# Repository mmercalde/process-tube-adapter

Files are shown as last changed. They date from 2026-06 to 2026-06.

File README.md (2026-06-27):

# Process-Tube Adapter (3D-printable, R600a)

A printable reimplementation of the Robinair 12458 **process-tube adapter** — the tool
that clamps onto a sealed system's copper **process stub** so you can pull a vacuum and
recharge without flaring the tube. Designed for **R600a (isobutane)** domestic
refrigeration, where working pressures are low and the real requirement is **vacuum
integrity**, not high-pressure containment.

The rigid parts are printed; the **seals are purchased O-rings**. Nothing safety-critical
relies on a printed sealing surface.

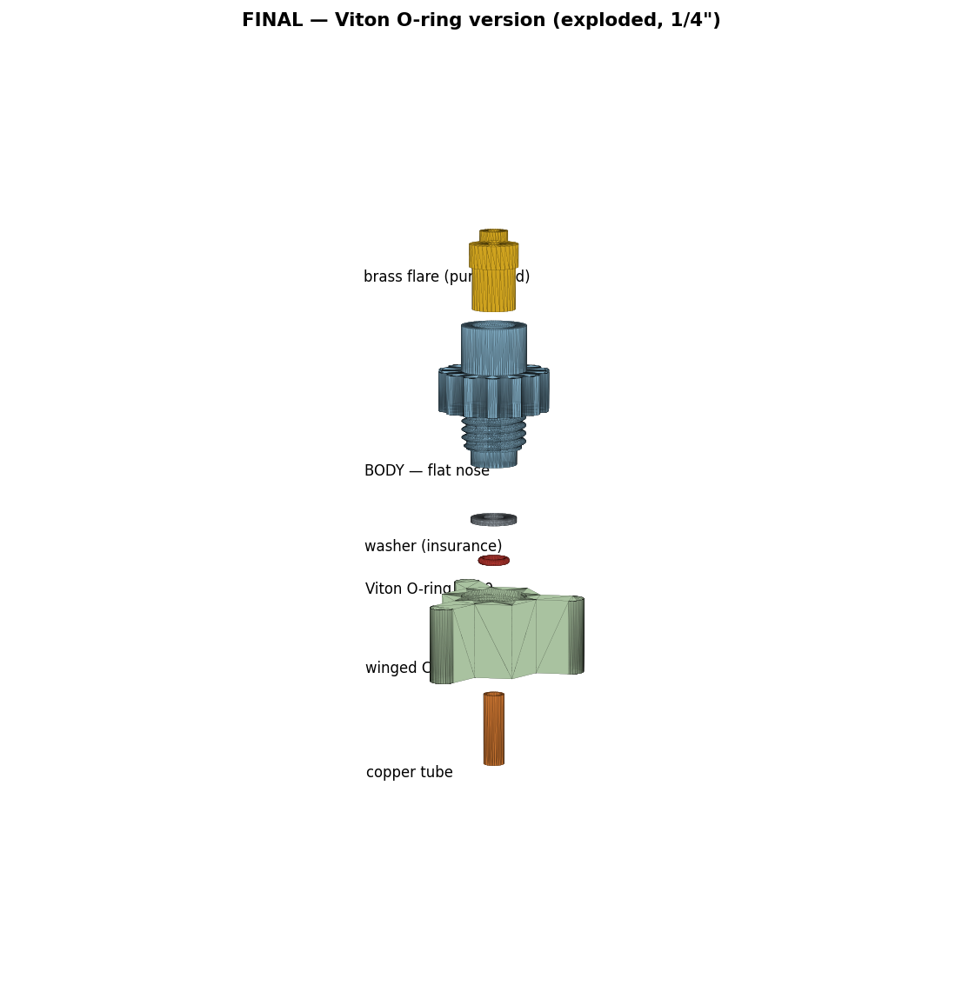
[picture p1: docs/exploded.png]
exploded


## How it works

One common **body** screws into a per-size **cap**. The copper stub slides up through the
cap's reinforced floor. Inside the cap's 17 mm bore sits a thick **channel washer** that carries **two standard O-rings** in edge grooves:

- the **outer ring** seals radially against the **17 mm cap bore**
- the **inner ring** seals radially against the **copper tube OD**

This splits the two sealing jobs the original Robinair crammed into one fat custom seal —
so both rings are common catalog sizes. The body's **clearance plunger nose** drives the
sandwich down; crush is **thread-driven with no hard stop**, so FDM tolerance variation
changes only how far you thread, never whether the rings seal. Refrigerant exits the open
cut end of the stub, up the body bore, to the hose.

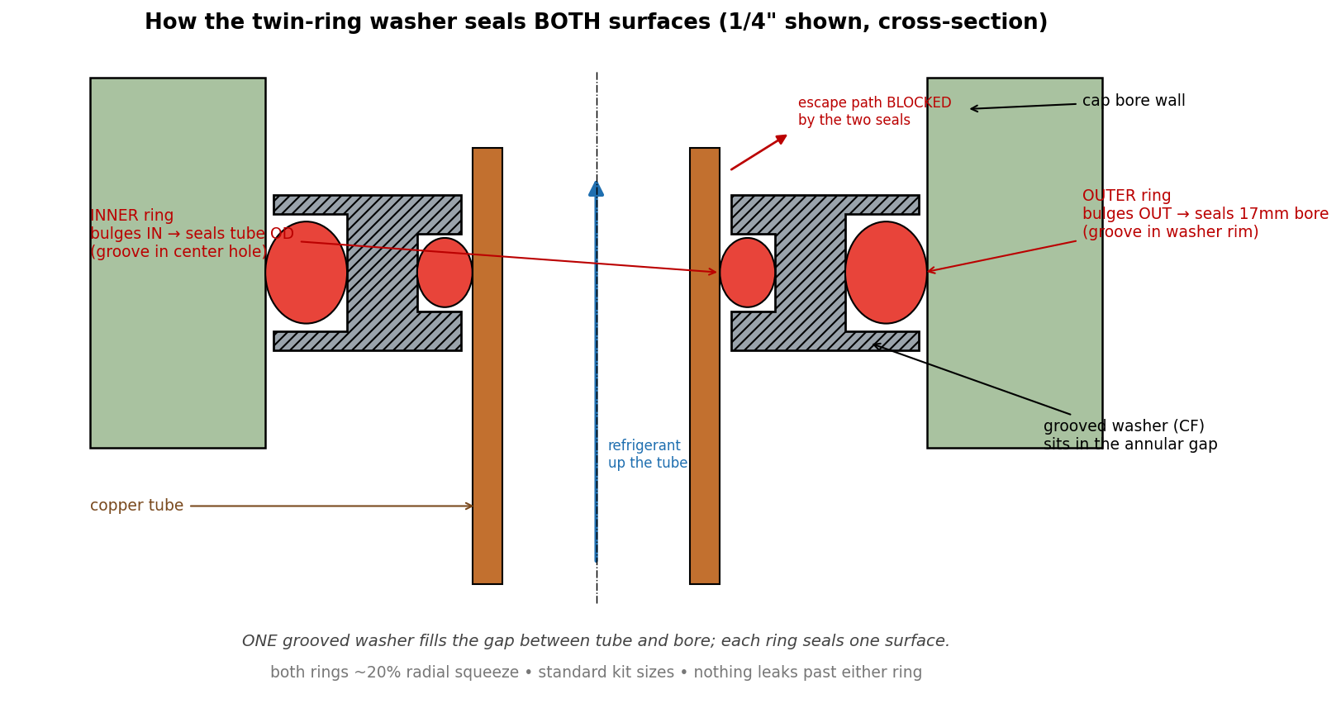
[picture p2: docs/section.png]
section


## Sealing — design notes

- **Reinforced 4.5 mm floor.** An earlier 2.5 mm floor buckled under crush load; the floor
  is now a solid anvil with only a tube-clearance hole.
- **No bottoming shoulder.** The plunger nose (Ø15 in the 17 bore) never lands metal-to-
  metal — the rings always take the load. Tighten until firm.
- **Edge grooves, ~20% squeeze.** The outer ring sits in a groove in the washer rim
  (root Ø12.81, vs the 17 bore); the inner ring sits in a groove in the center hole
  (root = tube OD + 2.85). Tune `SQUEEZE` in `generate.py` after a test fit.

## Bill of materials

Per assembly:
- 1 x printed **body** (shared across all tube sizes)
- 1 x printed **cap** for the tube size in use
- 1 x printed **channel washer** (the sealing element) + 1 x printed **backer washer**
- 1 x **outer O-ring** (seals the bore) + 1 x **inner O-ring** (seals the tube)
- 1 x **brass 1/4" SAE male-flare x 1/4" MNPT** adapter for the hose (threads into the body boss)
- Thread sealant (PTFE paste) for the brass-into-boss joint

### Tube size -> cap -> O-rings

| Tube OD | Cap / washers | Outer ring (bore) | Inner ring (tube) |
|---|---|---|---|
| 3/16" | `*_3-16` | A112 (12.37x2.62) | A008 (4.47x1.78)  |
| 1/4" | `*_1-4` | A112 | A010 (6.07x1.78)  |
| 5/16" | `*_5-16` | A112 | A011 (7.65x1.78)  |
| 3/8" | `*_3-8` | A112 | A012 (9.25x1.78)  |

The **outer ring is the same A112 for all four caps** (always sealing the 17 mm bore);
only the inner ring changes with tube size. Viton/FKM 75 Shore A recommended.

## Printing

- **Body + caps + washers:** PA-CF or PETG-CF, >=4 walls, 0.2 mm layers.
- Print the **body boss-up** so the NPT threads aren't on a support interface.
- Vertical circular holes run undersized on many printers — run X-Y hole compensation
  (~+0.15 mm) and verify the gland bore on a test print before committing all four.

## Assembly

1. Tap the body boss **1/4" NPT** (the Ø11.1 mm bore is the tap-drill — no drilling). Thread
   in the brass flare adapter with PTFE paste.
2. Drop the outer ring into the washers' outer pockets and the inner ring into the inner
   pockets; bring the washer pair together around the cut stub.
3. Slide the cap over the stub, thread the body in **by hand** until firm (wings + flutes
   give the grip — no wrench at R600a pressures).
4. Connect the charging hose to the brass flare. Evacuate / recharge.

## Verify before live use

Pull a vacuum on an assembled cap on a scrap stub and watch a micron gauge. If it creeps,
deepen the groove(s) slightly (`OG_D`/`IG_D`) for more squeeze and reprint the washers.
**R600a is flammable** — observe ventilation and ignition discipline.

## Regenerating / modifying

Every dimension is a named constant at the top of `generate.py`:

```bash
pip install build123d bd_warehouse
python3 generate.py        # writes ./stl and ./step
```

`.step` files open natively in FreeCAD / Fusion / Onshape for hands-on edits.

## License

MIT — see [LICENSE](LICENSE).

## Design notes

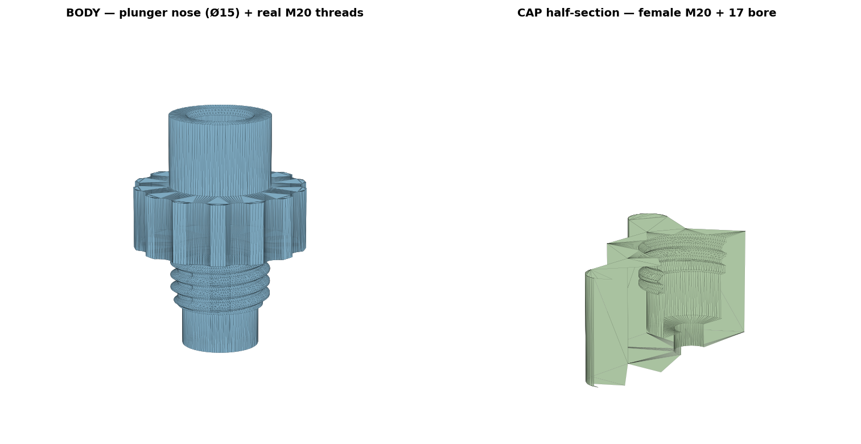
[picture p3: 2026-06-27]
docs/threads.png

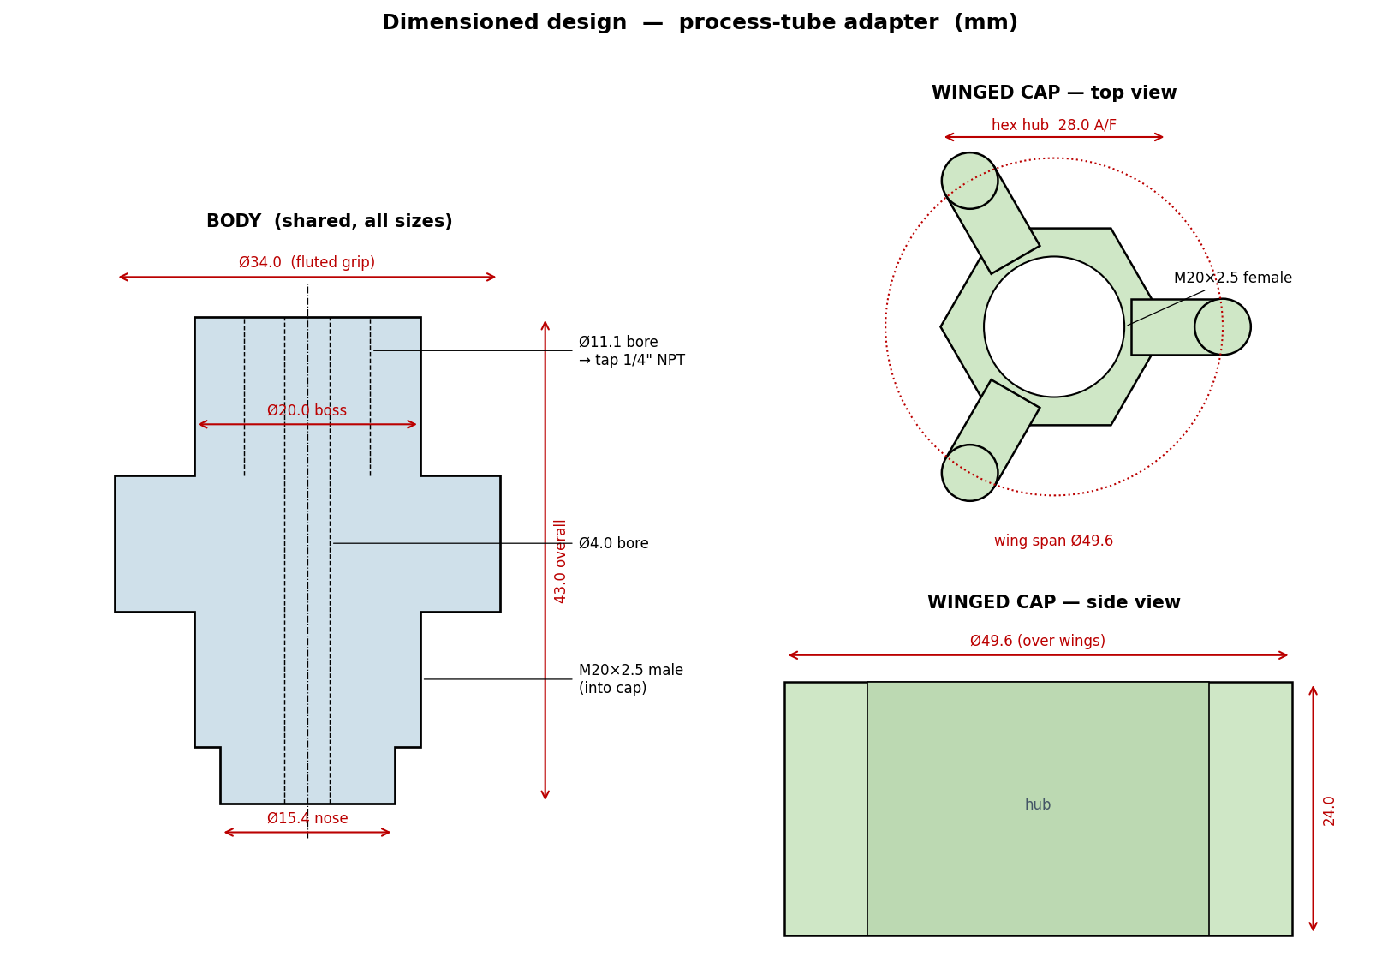
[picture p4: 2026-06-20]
docs/dimensioned.png

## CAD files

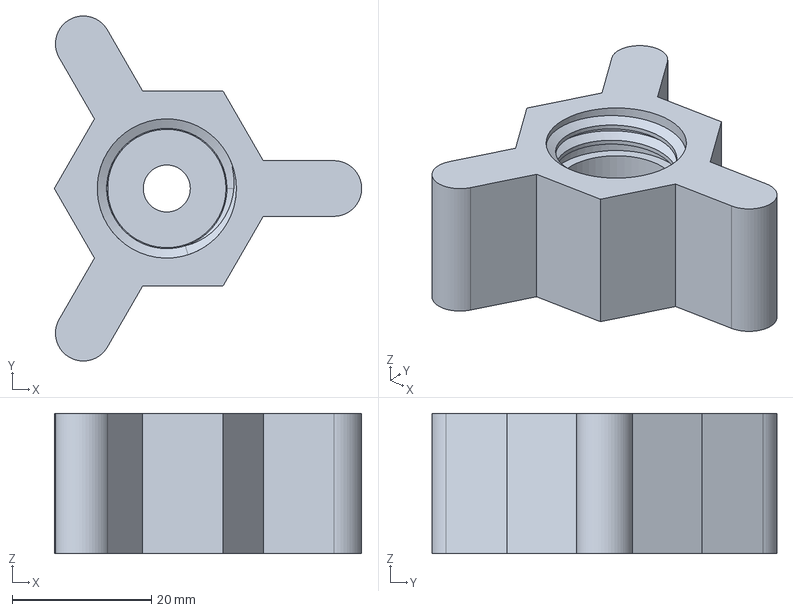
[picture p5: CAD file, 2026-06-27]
step/cap_1-4.step
44.2 x 49.6 x 20.1 mm

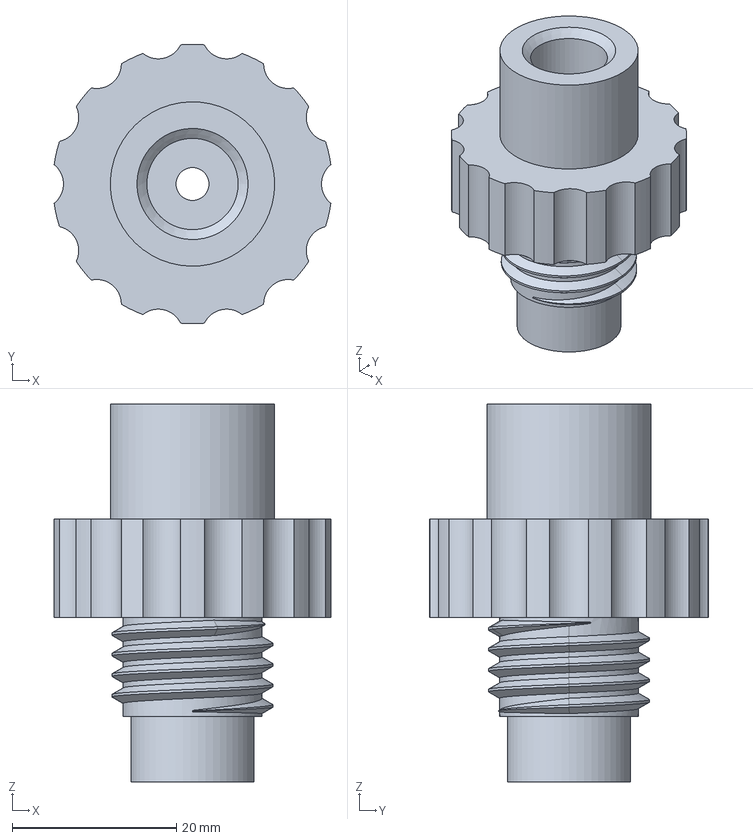
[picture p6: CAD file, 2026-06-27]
step/body.step
33.7 x 34.0 x 46.0 mm

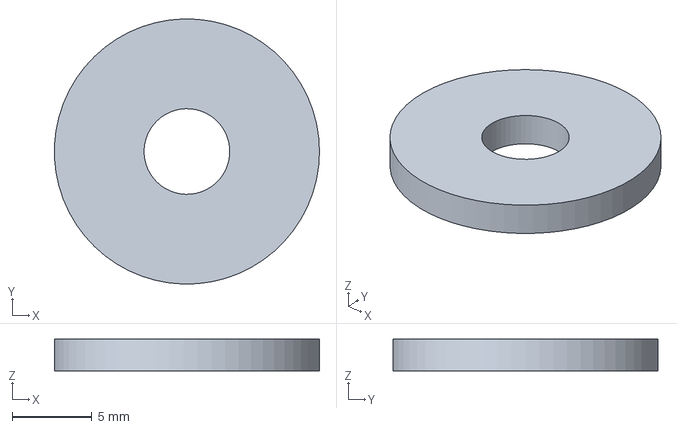
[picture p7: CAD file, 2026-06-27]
step/washer_backer_3-16.step
16.6 x 16.6 x 2.00 mm

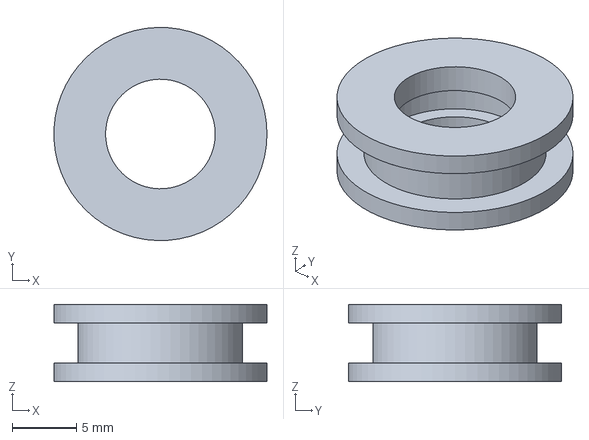
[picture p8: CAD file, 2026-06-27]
step/washer_channel_5-16.step
16.6 x 16.6 x 6.00 mm

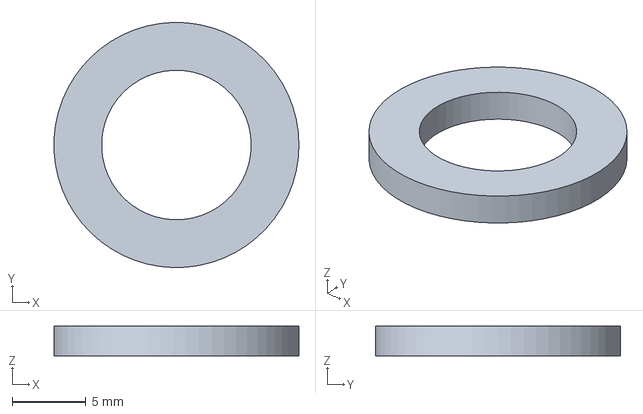
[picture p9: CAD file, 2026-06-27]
step/washer_backer_3-8.step
16.6 x 16.6 x 2.00 mm

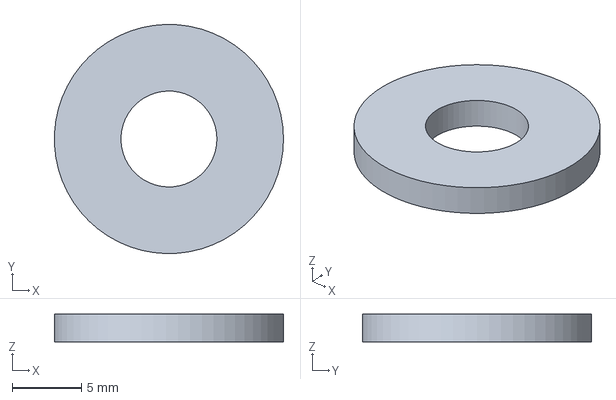
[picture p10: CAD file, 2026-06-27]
step/washer_backer_1-4.step
16.6 x 16.6 x 2.00 mm

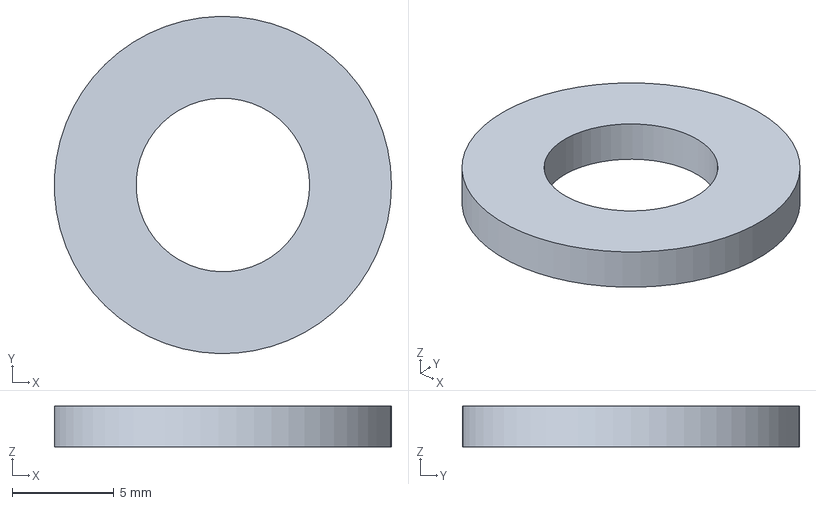
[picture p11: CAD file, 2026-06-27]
step/washer_backer_5-16.step
16.6 x 16.6 x 2.00 mm

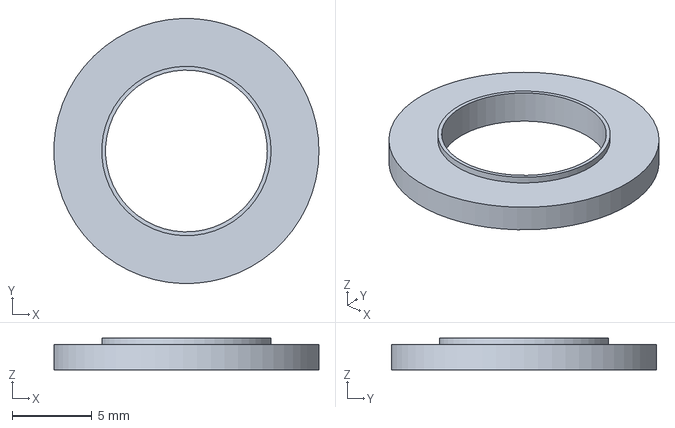
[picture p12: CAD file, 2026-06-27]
step/washer_3-8.step
16.6 x 16.6 x 2.00 mm

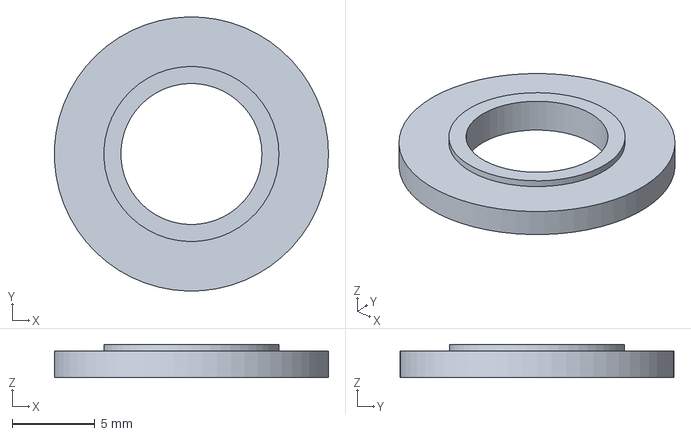
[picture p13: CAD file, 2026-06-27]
step/washer_5-16.step
16.6 x 16.6 x 2.00 mm

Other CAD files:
step/cap_5-16.step
step/cap_3-8.step
step/cap_3-16.step
step/washer_channel_1-4.step
step/washer_channel_3-16.step
step/washer_channel_3-8.step
step/washer_1-4.step
stl/body.stl
stl/cap_1-4.stl
stl/cap_3-16.stl
stl/cap_3-8.stl
stl/cap_5-16.stl
stl/washer_backer_1-4.stl
stl/washer_backer_3-16.stl
stl/washer_backer_3-8.stl
stl/washer_backer_5-16.stl
stl/washer_channel_1-4.stl
stl/washer_channel_3-16.stl
stl/washer_channel_3-8.stl
stl/washer_channel_5-16.stl

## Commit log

2026-06-20 Initial commit: 3D-printable process-tube adapter for R600a
    [body.step, body.stl, cap_1-4.step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]
2026-06-27 v5: twin-O-ring grooved washer pair, reinforced floor, plunger nose
    [body.step, body.stl, cap_1-4.step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]
2026-06-27 v6: thick channel washer with rim + center-hole grooves (both rings seal), flat backer
    [body.step, cap_1-4.step, cap_3-16.step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]
